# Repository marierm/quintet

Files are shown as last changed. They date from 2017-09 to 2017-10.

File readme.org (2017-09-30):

* Intro
  <2017-09-25 Mon> This repository contains all the files used for
  designing, building and playing the sponge.  This version is for the
  new sponge quintet.  The sponges are based on the Adafruit Feather
  M0 WiFi (with ATWINC1500 wifi chip).

* Instructions 
  Instructions on how to use the sponge with your comupter are in
  =scCode/instructions.org= or =scCode/instructions.pdf= .  They are
  in French only at this point.

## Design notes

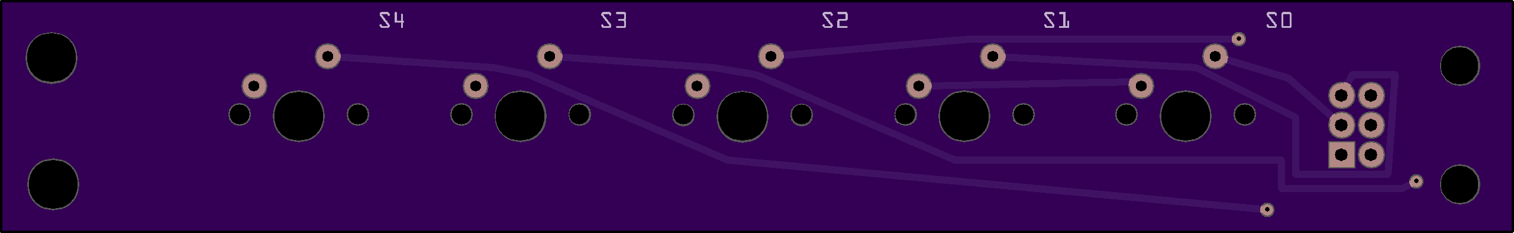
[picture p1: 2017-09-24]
pcb/buttonsTop.png

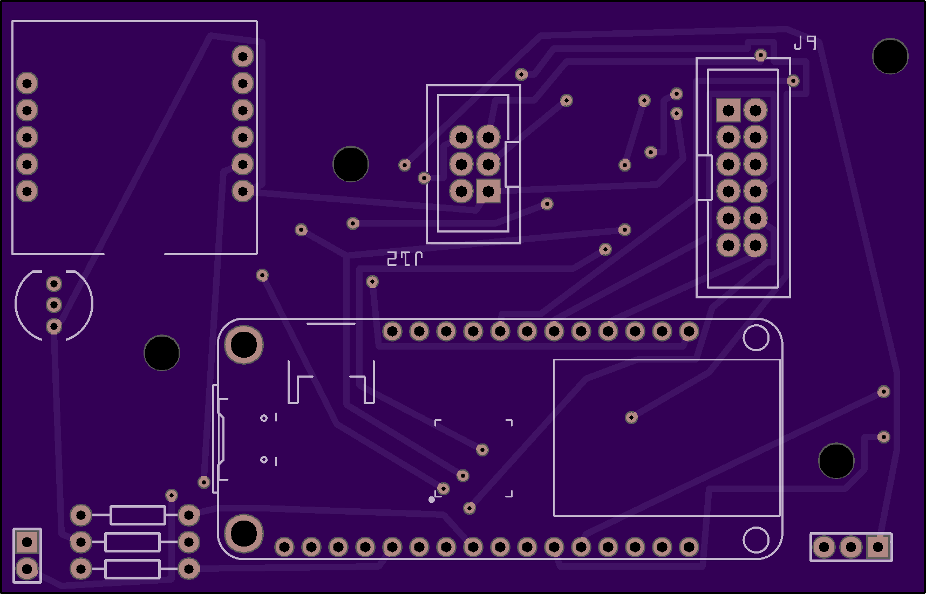
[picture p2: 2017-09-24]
pcb/mainTop.png

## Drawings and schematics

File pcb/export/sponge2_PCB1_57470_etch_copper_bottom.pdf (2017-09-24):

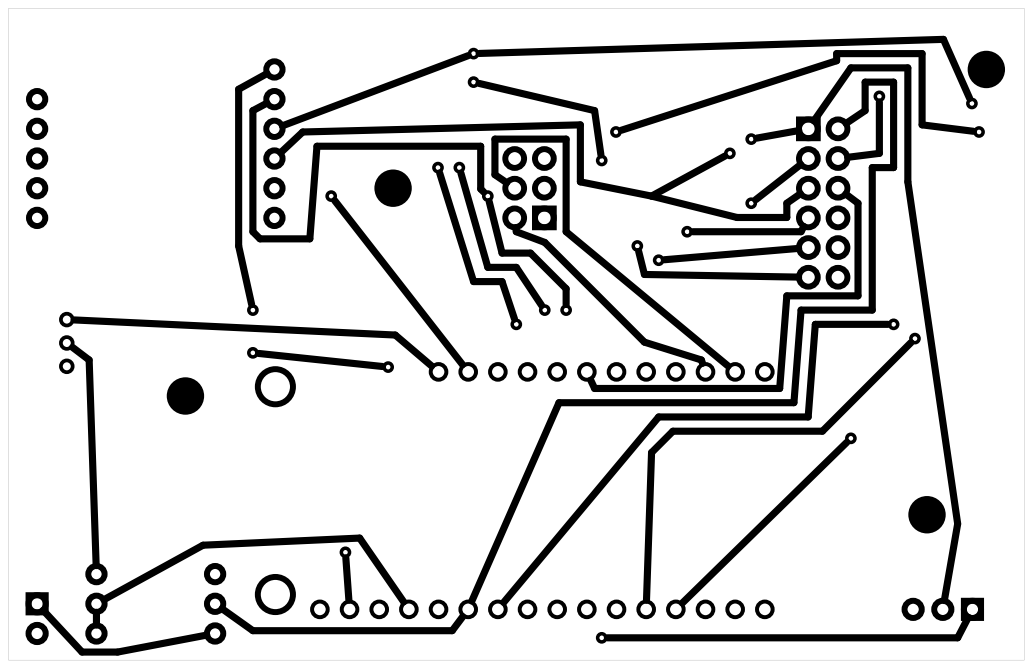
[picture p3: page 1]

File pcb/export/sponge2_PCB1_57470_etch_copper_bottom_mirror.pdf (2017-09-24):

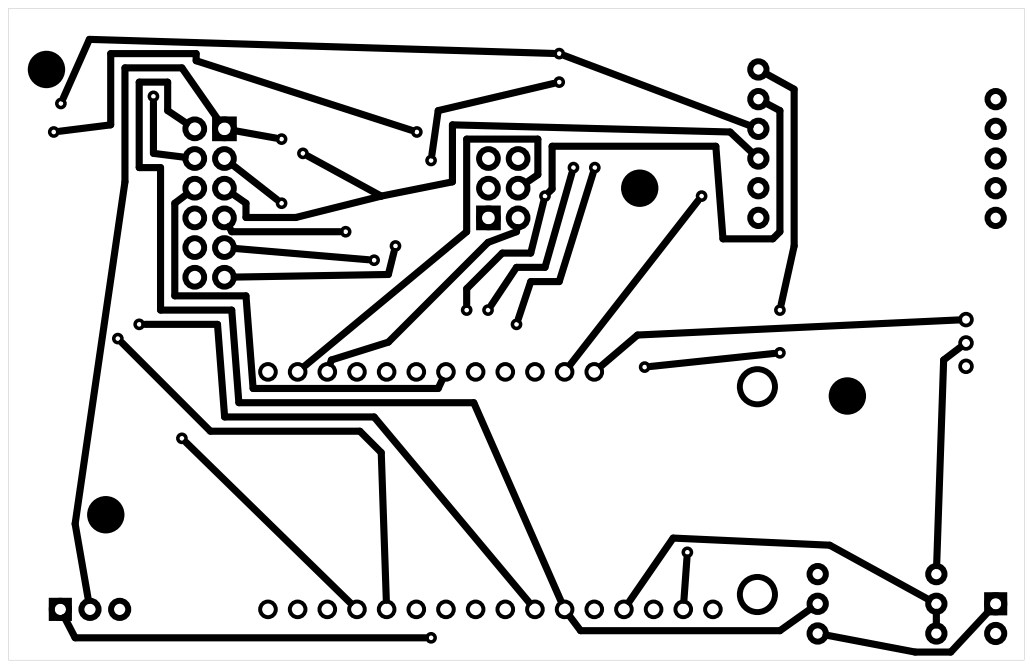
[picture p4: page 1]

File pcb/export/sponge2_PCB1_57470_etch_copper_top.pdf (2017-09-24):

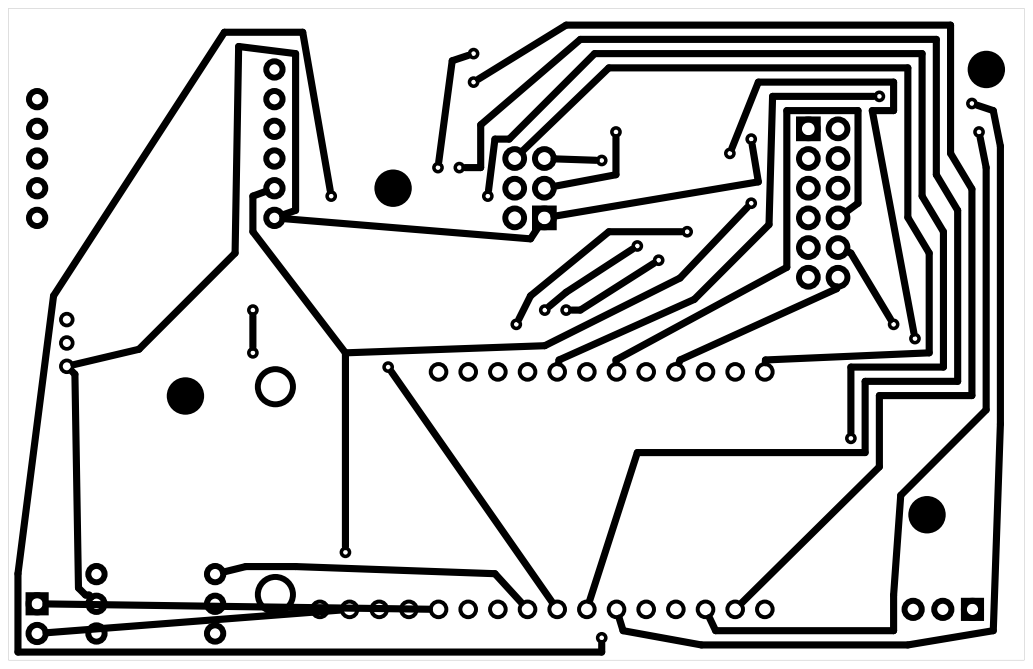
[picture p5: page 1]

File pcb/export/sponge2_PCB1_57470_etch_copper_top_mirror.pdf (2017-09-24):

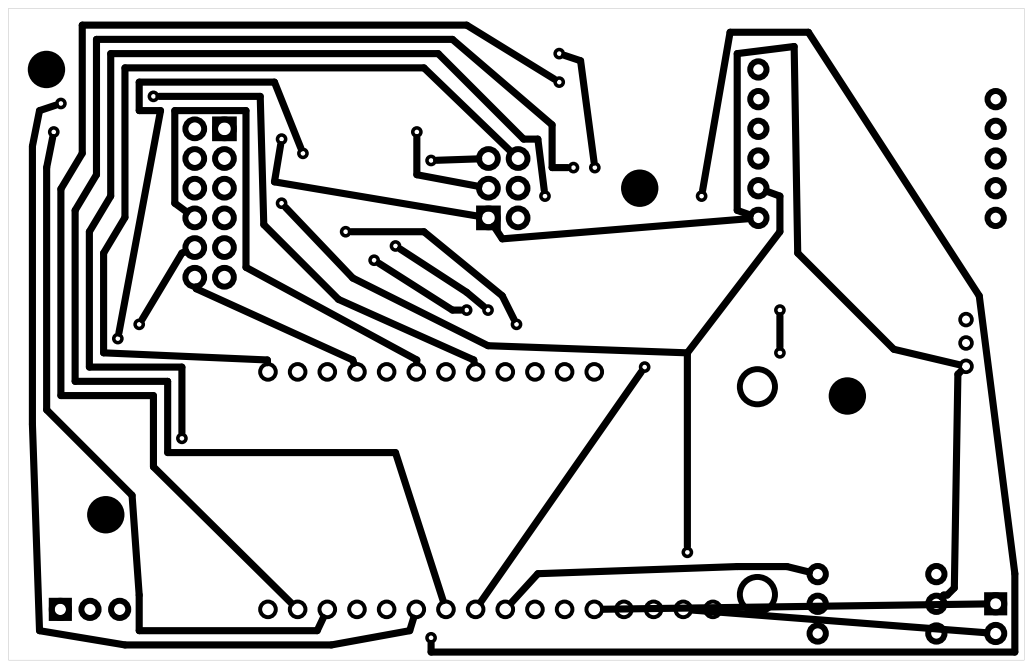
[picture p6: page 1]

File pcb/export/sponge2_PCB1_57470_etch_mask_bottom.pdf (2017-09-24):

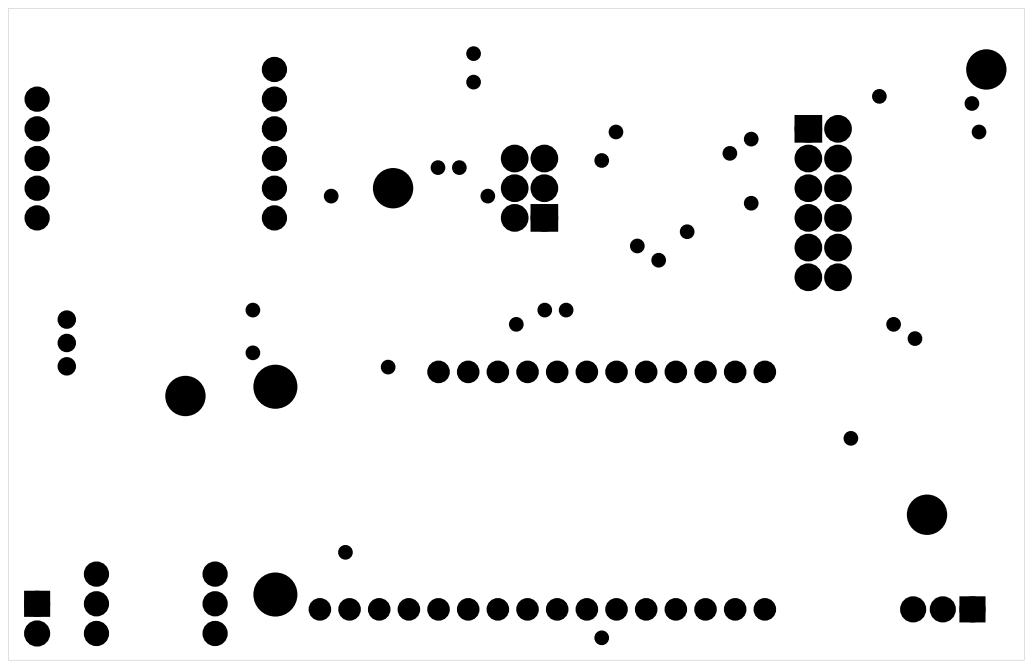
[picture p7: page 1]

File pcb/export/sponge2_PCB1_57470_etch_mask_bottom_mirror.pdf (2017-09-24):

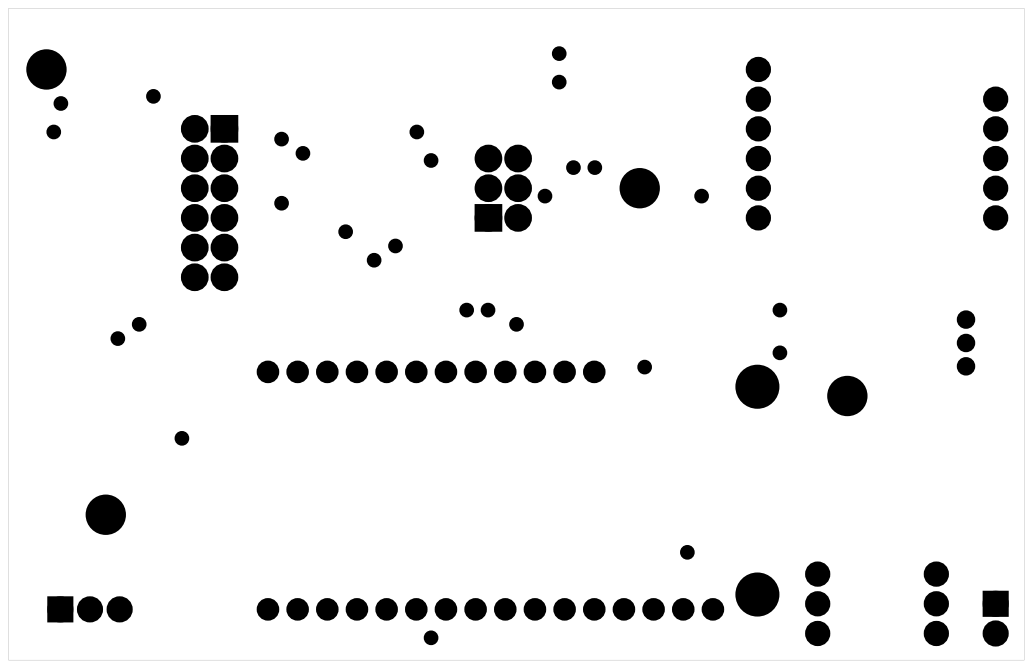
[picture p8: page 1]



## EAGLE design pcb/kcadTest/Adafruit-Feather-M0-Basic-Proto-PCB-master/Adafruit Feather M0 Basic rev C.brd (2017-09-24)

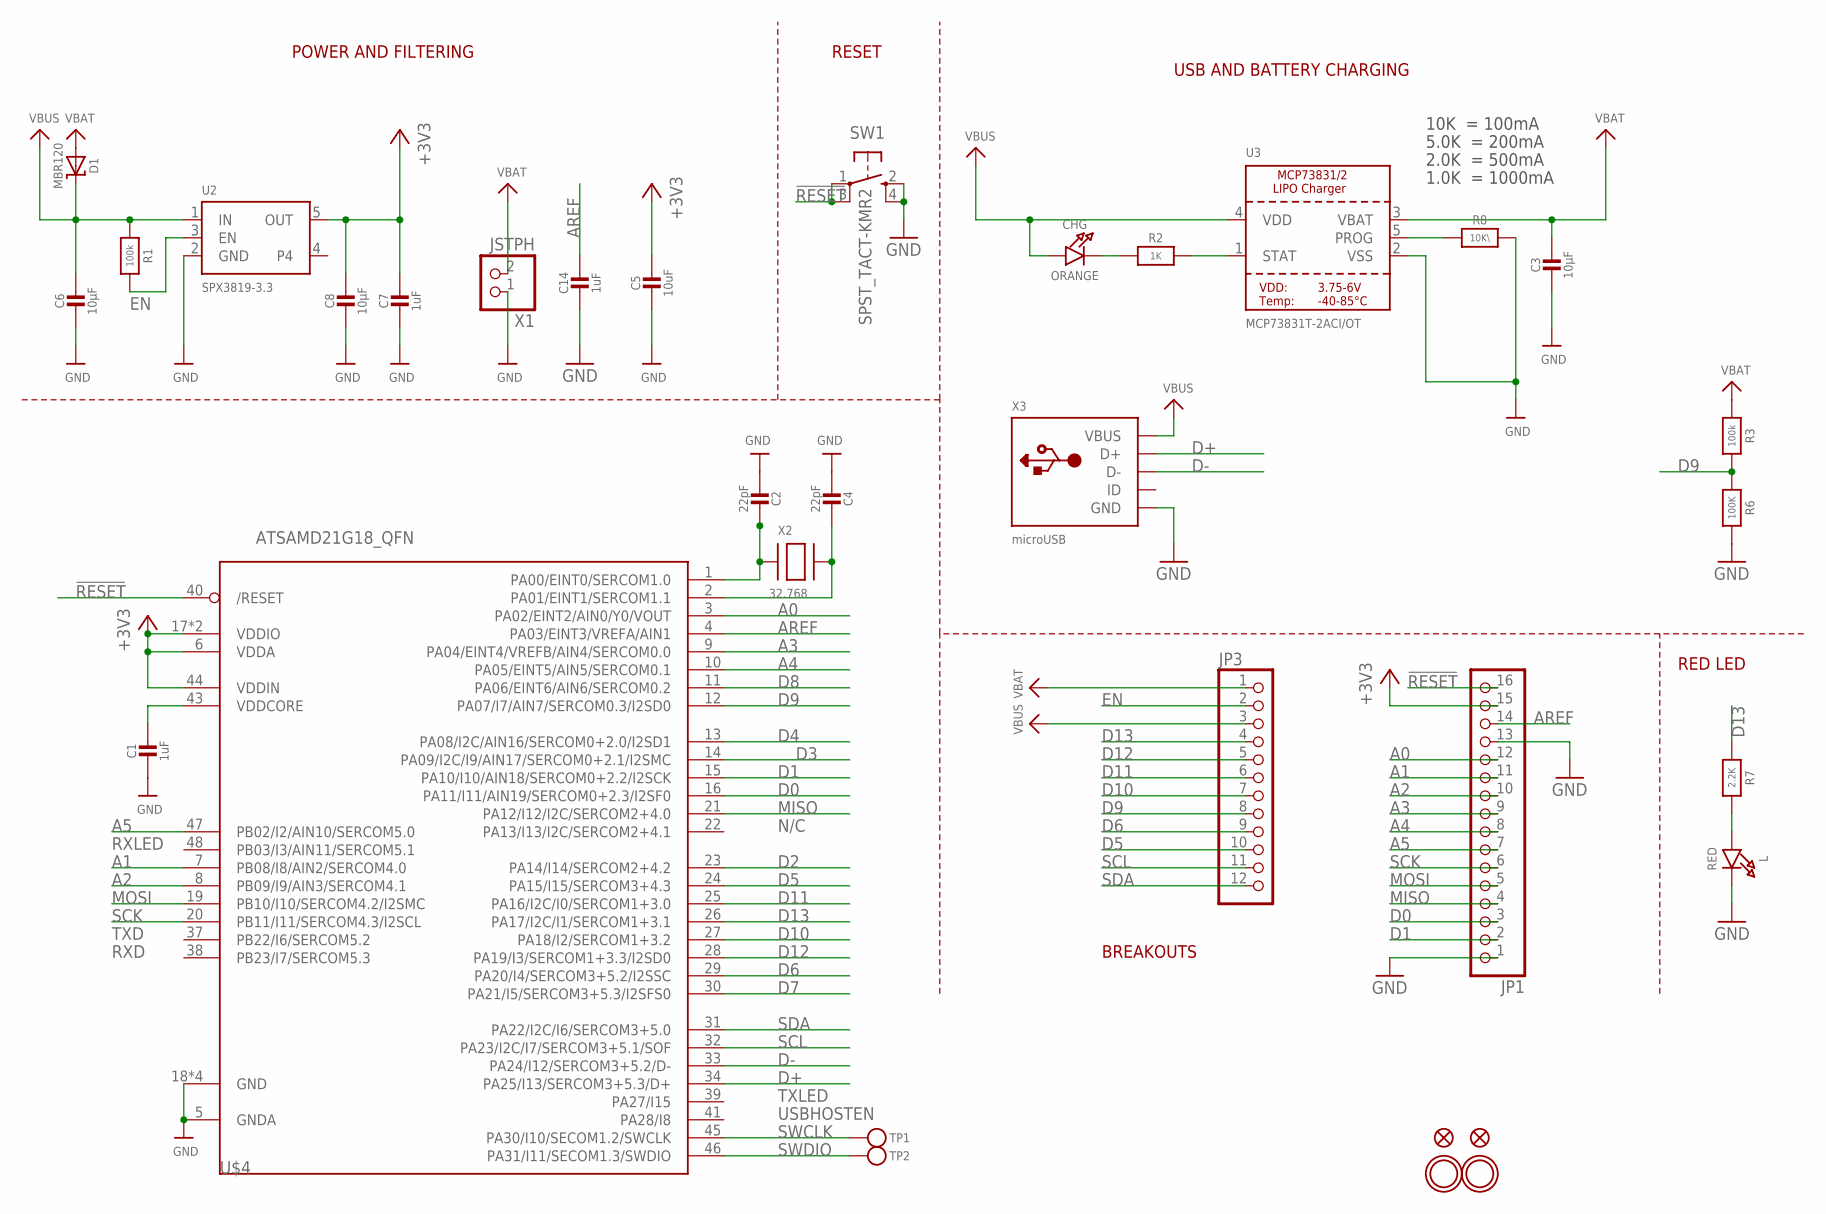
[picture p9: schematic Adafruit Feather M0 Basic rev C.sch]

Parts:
C1, C7, C14: 1uF; 0603-NO
C2, C4: 22pF; 0603-NO
C3, C6, C8: 10µF; 0805-NO
C5: 10uF; 0805-NO
CHG: ORANGE; CHIPLED_0805_NOOUTLINE
D1: MBR120; SOD-123
JP1: HEADER-1X16ROUND; 1X16_ROUND
JP3: HEADER-1X12; 1X12_ROUND
L: RED; CHIPLED_0805_NOOUTLINE
R1, R3: 100k; 0603-NO
R2: 1K; 0603-NO
R6: 100K; 0603-NO
R7: 2.2K; 0603-NO
R8: 10K\; 0603-NO
SW1: SPST_TACT-KMR2; KMR2
TP1, TP2: TESTPOINTROUND1.5MM; TESTPOINT_ROUND_1.5MM
U2: SPX3819-3.3; SOT23-5
U3: MCP73831T-2ACI/OT; SOT23-5
U$4: ATSAMD21G18_QFN; TQFN48_7MM
U$31, U$32: MOUNTINGHOLE2.5; MOUNTINGHOLE_2.5_PLATED
U$34, U$35: FIDUCIAL""; FIDUCIAL_1MM
X1: JSTPH; JSTPH2
X2: 32.768; XTAL3215
X3: microUSB; 4UCONN_20329_V2

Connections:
!RESET: JP1.16, SW1.1, SW1.3 (P1), U$4.40 (/RESET)
+3V3: C5.1, C7.1, C8.1, JP1.15, U2.5 (OUT), U$4.6 (VDDA), U$4.17 (VDDIO), U$4.36 (VDDIO), U$4.44 (VDDIN)
A0: JP1.12, U$4.3 (PA02/EINT2/AIN0/Y0/VOUT)
A1: JP1.11, U$4.7 (PB08/I8/AIN2/SERCOM4.0)
A2: JP1.10, U$4.8 (PB09/I9/AIN3/SERCOM4.1)
A3: JP1.9, U$4.9 (PA04/EINT4/VREFB/AIN4/SERCOM0.0)
A4: JP1.8, U$4.10 (PA05/EINT5/AIN5/SERCOM0.1)
A5: JP1.7, U$4.47 (PB02/I2/AIN10/SERCOM5.0)
AREF: C14.1, JP1.14, U$4.4 (PA03/EINT3/VREFA/AIN1)
D0: JP1.3, U$4.16 (PA11/I11/AIN19/SERCOM0+2.3/I2SF0)
D1: JP1.2, U$4.15 (PA10/I10/AIN18/SERCOM0+2.2/I2SCK)
D2: U$4.23 (PA14/I14/SERCOM2+4.2)
D3: U$4.14 (PA09/I2C/I9/AIN17/SERCOM0+2.1/I2SMC)
D4: U$4.13 (PA08/I2C/AIN16/SERCOM0+2.0/I2SD1)
D5: JP3.10, U$4.24 (PA15/I15/SERCOM3+4.3)
D6: JP3.9, U$4.29 (PA20/I4/SERCOM3+5.2/I2SSC)
D7: U$4.30 (PA21/I5/SERCOM3+5.3/I2SFS0)
D8: U$4.11 (PA06/EINT6/AIN6/SERCOM0.2)
D9: JP3.8, R3.2, R6.1, U$4.12 (PA07/I7/AIN7/SERCOM0.3/I2SD0)
D10: JP3.7, U$4.27 (PA18/I2/SERCOM1+3.2)
D11: JP3.6, U$4.25 (PA16/I2C/I0/SERCOM1+3.0)
D12: JP3.5, U$4.28 (PA19/I3/SERCOM1+3.3/I2SD0)
D13: JP3.4, R7.1, U$4.26 (PA17/I2C/I1/SERCOM1+3.1)
D+: U$4.34 (PA25/I13/SERCOM3+5.3/D+), X3.D+
D-: U$4.33 (PA24/I12/SERCOM3+5.2/D-), X3.D-
EN: JP3.2, R1.2, U2.3 (EN)
GND: C1.2, C2.2, C3.2, C4.2, C5.2, C6.2, C7.2, C8.2, C14.2, JP1.1, JP1.13, L.C, R6.2, R8.2, SW1.2 (S), SW1.4 (S1), U2.2 (GND), U3.2 (VSS), U$4.5 (GNDA), U$4.18 (GND), U$4.35 (GND), U$4.42 (GND), U$4.THERMAL (GND), X1.1, X3.BASE@1 (GND), X3.BASE@2 (GND), X3.GND, X3.SPRT@1 (GND), X3.SPRT@2 (GND), X3.SPRT@3 (GND), X3.SPRT@4 (GND)
MISO: JP1.4, U$4.21 (PA12/I12/I2C/SERCOM2+4.0)
MOSI: JP1.5, U$4.19 (PB10/I10/SERCOM4.2/I2SMC)
unnamed: CHG.C, R2.1
unnamed: L.A, R7.2
unnamed: R2.2, U3.1 (STAT)
unnamed: R8.1, U3.5 (PROG)
unnamed: C2.1, U$4.1 (PA00/EINT0/SERCOM1.0), X2.P$1
unnamed: C4.1, U$4.2 (PA01/EINT1/SERCOM1.1), X2.P$2
SCK: JP1.6, U$4.20 (PB11/I11/SERCOM4.3/I2SCL)
SCL: JP3.11, U$4.32 (PA23/I2C/I7/SERCOM3+5.1/SOF)
SDA: JP3.12, U$4.31 (PA22/I2C/I6/SERCOM3+5.0)
SWCLK: TP1.P$1, U$4.45 (PA30/I10/SECOM1.2/SWCLK)
SWDIO: TP2.P$1, U$4.46 (PA31/I11/SECOM1.3/SWDIO)
VBAT: C3.1, D1.A, JP3.1, R3.1, U3.3 (VBAT), X1.2
VBUS: C6.1, CHG.A, D1.C, JP3.3, R1.1, U2.1 (IN), U3.4 (VDD), X3.VBUS
VDDCORE: C1.1, U$4.43 (VDDCORE)

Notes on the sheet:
POWER AND FILTERING
RESET
10K = 100mA
5.0K = 200mA
2.0K = 500mA
1.0K = 1000mA
N/C
TXLED
USBHOSTEN
RXLED
TXD
RXD
USB AND BATTERY CHARGING
BREAKOUTS
RED LED

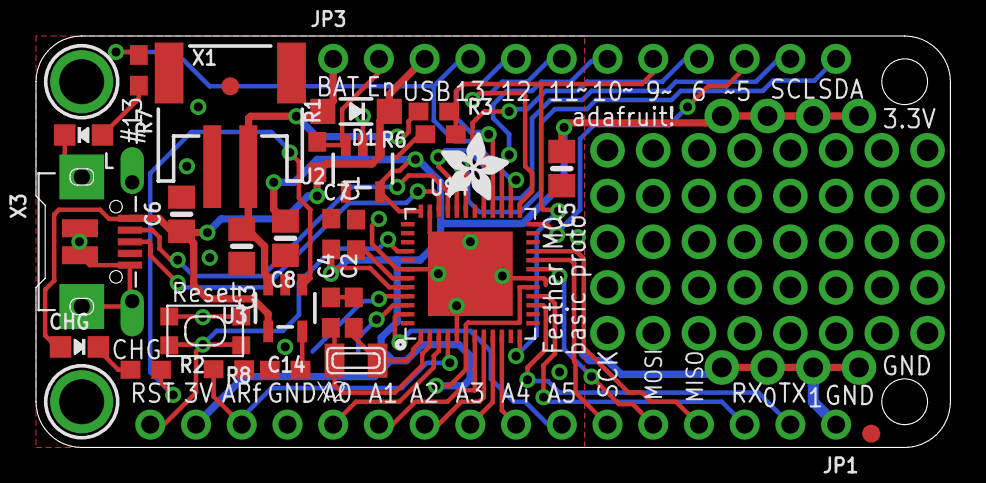
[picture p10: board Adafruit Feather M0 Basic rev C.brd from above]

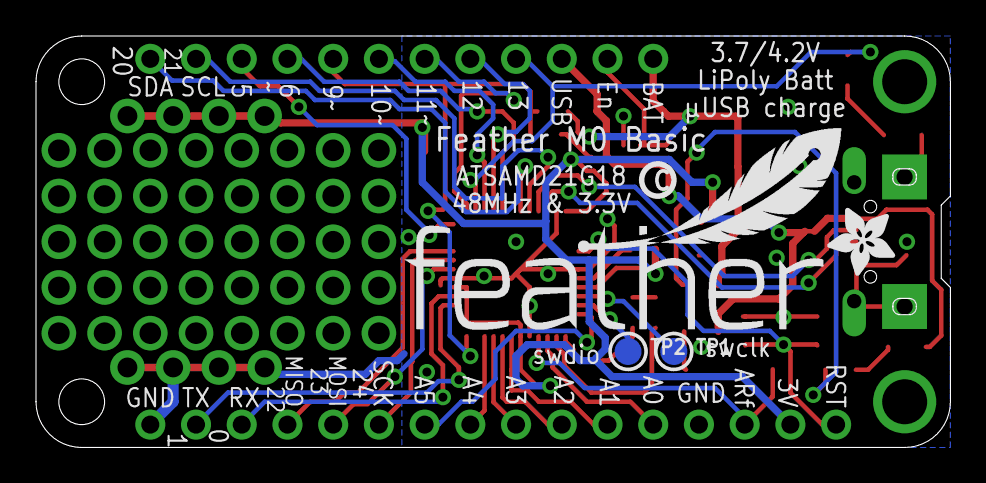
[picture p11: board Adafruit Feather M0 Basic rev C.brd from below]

Board: 2 copper layers, 50.8 x 22.9 mm, 37 parts (5 on the bottom side), 38 nets.

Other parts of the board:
U$7, U$12: ADAFRUIT_3.5MM
U$9: FEATHERLOGO
U$13: PCBFEAT-REV-040

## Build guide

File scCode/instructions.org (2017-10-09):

#+OPTIONS: ':nil *:t -:t ::t <:t H:3 \n:nil ^:t arch:headline
#+OPTIONS: author:t broken-links:nil c:nil creator:nil
#+OPTIONS: d:(not "LOGBOOK") date:t e:t email:nil f:t inline:t num:t
#+OPTIONS: p:nil pri:nil prop:nil stat:t tags:t tasks:t tex:t
#+OPTIONS: timestamp:t title:t toc:nil todo:t |:t
#+TITLE: Instructions pour utiliser l'éponge.
#+DATE: 
#+AUTHOR: Martin Marier
#+EMAIL: martin@martinmarier.com
#+LANGUAGE: fr
#+SELECT_TAGS: export
#+EXCLUDE_TAGS: noexport
#+CREATOR: Emacs 25.3.1 (Org mode 9.1)

* Installer SuperCollider et les plugins
  La version la plus récente de SC est disponible ici:
  http://supercollider.github.io/download Nous utilisons actuellement la
  version 3.8.0.

  Les plugins sont disponibles ici:
  https://github.com/supercollider/sc3-plugins/releases Nous utilisons
  actuellement la version 3.8.0.

  Une fois l'archive ZIP dépaquetée, le dossier =SC3plugins= et tout
  son contenu doit être placé dans ce dossier (sur Mac):

  =/Users/yourUserName/Library/Application Support/SuperCollider/Extensions=

  Créez le dossier =Extensions= au besoin.

  Pour connaître le dossier dans lequel vous devez déposer les
  =SC3plugins= sur une autre plateforme (Windows ou Linux), démarrez
  SuperCollider et cliquez sur l'item /Open user support directory/ du
  menu /File/.

* Installer tous les Quarks nécessaires
  La liste des quarks nécessaires est dans le fichier
  =scCode/installation.scd=

  Vous devez ouvrir ce document avec SuperCollider et exécuter le bloc de code
  qui est entre parenthèses.

  Pour exécuter le bloc, placez le curseur sur la première parenthèse et
  appuyez sur Command+Enter (ou Ctrl+Enter).

* Installer les mmExtensions
  Téléchargez les mmExtensions ici: https://github.com/marierm/mmExtensions

  Le fichier ZIP doit être dépaqueté dans ce dossier (sur mac):

  =/Users/yourUserName/Library/Application Support/SuperCollider/Extensions=

  Créez le dossier =Extensions= au besoin.

* Configurer l'éponge
  Lors de sa mise sous tension, l'éponge tente de se connecter au
  dernier point d'accès WiFi (un routeur sans fil) auquel elle s'est
  connectée.

  Si ce point d'accès n'est pas disponible, l'éponge devient elle-même
  un point d'accès dont le nom est =wifi101-XXXX=, où =XXXX=
  représente les quatre derniers caractères de l'adresse MAC de
  l'éponge.  L'adresse MAC -- unique pour chaque appareil pouvant se
  connecter à un résea WiFi -- est imprimée sur le module WiFi de
  l'éponge.

  Il faudra alors se connecter à ce réseau Wifi et, de là, accéder à
  la page web servie par l'éponge à l'adresse http://192.168.1.1 .
  Sur cette page, entrez le nom de votre point d'accès et le mot de
  passe correspondant.  L'éponge se connectera alors automatiquement
  au point d'accès que vous avez entré.  (À partir de ce moment, la
  page http://192.168.1.1 n'est plus accessible.  Il est donc normal
  que le navigateur utilisé affiche un message d'erreur.)

* Démarrer l'éponge en mode solo
  Ouvrez le fichier scCode/solo.scd dans SuperCollider et exécuter le bloc de code
  qui est entre parenthèses.

  Pour exécuter le bloc, placez le curseur sur la première parenthèse
  et appuyez sur Command+Enter (ou Ctrl+Enter).

  L'éponge est prête quand le message =sponge_solo ready.= apparaît dans la fenêtre
  =Post= de SuperCollider.

* Messages OSC
  (Vous n'avez pas besoin de comprendre tout ça.)

  L'éponge envoie des messages OSC en /multicast/ à l'adresse
  =224.0.0.1= sur le port 50501, à partir du port 50502.  Un seul
  message est envoyé à chaque 20 millisecondes.  L'adresse est
  =/sponge=.  Elle est suivie de neuf paramètres (tous des entiers):
  =acc1x=, =acc1y=, =acc1z=, =acc2x=, =acc2y=, =acc2z=, =fsr1=,
  =fsr2=, =buttons= .

  Les accéléromètres ont des valeurs 16 bits signées, les fsr ont des
  valeurs 12 bits non signées, et les boutons sont représentés par les
  10 bits les moins significatifs d'un entier à 32 bits.

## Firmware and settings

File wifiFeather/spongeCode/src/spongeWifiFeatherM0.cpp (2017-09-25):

#include "SparkFunLSM6DS3.h"
#include <SPI.h>
#include <Wire.h>
#include <WiFi101.h>
#include <WiFiUdp.h>
#include <OSCMessage.h>
#include <OSCBundle.h>
#include <OSCData.h>
void SLIPSerialWrite(int value);
void sendSpongeOSC();
void initAccelGyro();

//SLIP for wired serial backup.
const byte END=192;
const byte ESC=219;
const byte ESC_END=220;
const byte ESC_ESC=221;


// const char* ssid     = "mmLinksysEA7500-2.4";
// const char* ssid     = "sideroxylon";
// const char* password = "ddcgrvc4zw";
 
WiFiUDP udp; // A UDP instance to let us send and receive packets over UDP
// const IPAddress outIp(192,168,109,103); // remote IP of your computer
const IPAddress outIp(224,0,0,1); // remote IP for multicast
// const IPAddress outIp(10,42,0,1); // remote IP of your computer
const unsigned int outPort = 50501; // remote port to receive OSC
const unsigned int localPort = 50502; // local port to listen for OSC packets


// const int butPins[10] = { 0,1,20,21,5,6,9,10,11,12 };
// GPIO 9 can be used as A7 to monitor battery voltage.
// Use GPIO 16 (A2) instead.
const int butPins[10] = { 0,1,20,21,5,6,16,10,11,12 };
const int ledPin = 17; // Controler pin for LED strip.

OSCErrorCode error;

LSM6DS3 SensorOne( SPI_MODE, 18 );  // pin A4 on feather
LSM6DS3 SensorTwo( SPI_MODE, 19 );  // pin A5 on feather

void setup(){
  //Configure pins for Adafruit ATWINC1500 Feather
  WiFi.setPins(8,7,4,2);
  Serial.begin(115200);
  analogReadResolution(12);
  // Make butPins INPUT pins with pull up resistor.
  for (int i=0; i < 10; i++){
    pinMode(butPins[i], INPUT_PULLUP);
  }

  // pinMode(12, INPUT);
  /* Wire.begin(); */

  delay(100);
  // We start by connecting to a WiFi network
 

  // Serial.println();
  // Serial.print("Connecting to ");
  // Serial.println(ssid);
  
  // WiFi.begin(ssid, password);
  // WiFi.begin(ssid,password);
  WiFi.beginProvision();
  
  while (WiFi.status() != WL_CONNECTED) {
    delay(500);
    Serial.write(END);
  }
 
  // Serial.println("");
  // Serial.println("WiFi connected");  
  // Serial.print("IP address: ");
  // Serial.println(WiFi.localIP());

  // Serial.print("SSID: ");
  // Serial.println(WiFi.SSID());

  // Serial.println("Starting UDP");
  // udp.begin(localPort);
  udp.beginMulti(outIp, localPort);
  // Serial.print("Local port: ");
  // Serial.println(localPort);


  delay(1000);
  initAccelGyro();

  // SensorOne.begin();
  // SensorTwo.begin();
  if( SensorOne.begin() != 0 ) {
    Serial.write(END);
    Serial.println("Problem starting the sensor with CS @ Pin 18 (A4).");
    Serial.write(END);
  } else {
    Serial.write(END);
    Serial.println("Sensor with CS @ Pin 18 (A4) started.");
    Serial.write(END);
  }
  if( SensorTwo.begin() != 0 ) {
    Serial.write(END);
    Serial.println("Problem starting the sensor with CS @ Pin 19 (A5).");
    Serial.write(END);
  } else {
    Serial.write(END);
    Serial.println("Sensor with CS @ Pin 19 (A5) started.");
    Serial.write(END);
  }
}

void loop(){
  OSCMessage message;
  int size = udp.parsePacket();

  if (size) {
    while (size--) {
      message.fill(udp.read());
    }
    if (!message.hasError()) {
      /* message.dispatch("/set_register", osc_set_register); */
    } else {
      error = message.getError();
      Serial.print("error: ");
      Serial.println(error);
    }
  }

  // Serial.println( (SensorOne.readRawAccelX() >> 6) + 512);
  // Serial.print(SensorOne.readRawAccelY());
  // Serial.print(SensorOne.readRawAccelZ());
  // Serial.print(SensorOne.readRawGyroX());
  // Serial.print(SensorOne.readRawGyroY());
  // Serial.print(SensorOne.readRawGyroZ());

  sendSpongeOSC();
  
  // int anal0 = analogRead(1);
  // OSCBundle bndl;

  // wait a bit.
  // delay(5);
  // Serial.println(WiFi.SSID());
  delay(20); // 15 seems to be too short.
  
  // delay(1);
  // delayMicroseconds(10);

  // if (WiFi.status() != WL_CONNECTED) {
  //   // WiFi.end();
  //   while (WiFi.begin(ssid) != WL_CONNECTED) {
  //     delay(500);
  //     Serial.print(".");
  //   }
  //   Serial.print("Reconnected to ");
  //   Serial.print(ssid);
  // }
}

void initAccelGyro(){
  //Over-ride default settings if desired
  SensorOne.settings.gyroEnabled = 1;  //Can be 0 or 1
  SensorOne.settings.gyroRange = 2000;   //Max deg/s.  Can be: 125, 245, 500, 1000, 2000
  SensorOne.settings.gyroSampleRate = 1666;   //Hz.  Can be: 13, 26, 52, 104, 208, 416, 833, 1666
  SensorOne.settings.gyroBandWidth = 400;  //Hz.  Can be: 50, 100, 200, 400;
  SensorOne.settings.accelEnabled = 1;
  SensorOne.settings.accelRange = 2;      //Max G force readable.  Can be: 2, 4, 8, 16
  SensorOne.settings.accelSampleRate = 13330;  //Hz.  Can be: 13, 26, 52, 104, 208, 416, 833, 1666, 3332, 6664, 13330
  SensorOne.settings.accelBandWidth = 400;  //Hz.  Can be: 50, 100, 200, 400;
  SensorOne.settings.fifoModeWord = 0;  //FIFO mode.

    //Over-ride default settings if desired
  SensorTwo.settings.gyroEnabled = 1;  //Can be 0 or 1
  SensorTwo.settings.gyroRange = 2000;   //Max deg/s.  Can be: 125, 245, 500, 1000, 2000
  SensorTwo.settings.gyroSampleRate = 1666;   //Hz.  Can be: 13, 26, 52, 104, 208, 416, 833, 1666
  SensorTwo.settings.gyroBandWidth = 400;  //Hz.  Can be: 50, 100, 200, 400;
  SensorTwo.settings.accelEnabled = 1;
  SensorTwo.settings.accelRange = 2;      //Max G force readable.  Can be: 2, 4, 8, 16
  SensorTwo.settings.accelSampleRate = 13330;  //Hz.  Can be: 13, 26, 52, 104, 208, 416, 833, 1666, 3332, 6664, 13330
  SensorTwo.settings.accelBandWidth = 400;  //Hz.  Can be: 50, 100, 200, 400;
  SensorTwo.settings.fifoModeWord = 0;  //FIFO mode.

  //FIFO mode.  Can be:
  //  0 (Bypass mode, FIFO off)
  //  1 (Stop when full)
  //  3 (Continuous during trigger)
  //  4 (Bypass until trigger)
  //  6 (Continous mode)
}


void sendSpongeOSC() {
  int compButVal=0; // composed into a single 32 bit integer (only 10 are used).

  OSCMessage msg("/sponge"); // 8 bytes
  // OSCMessage time("/time");
  // uint64_t timetag;
  // msg.add(anal0);
  // types are ,iiiiiiiiiiiii // 4 bytes
  msg.add(int(SensorOne.readRawAccelX())); // int 0
  msg.add(int(SensorOne.readRawAccelY())); // int 1
  msg.add(int(SensorOne.readRawAccelZ())); // int 2
  // msg.add(int(SensorOne.readRawGyroX()));
  // msg.add(int(SensorOne.readRawGyroY()));
  // msg.add(int(SensorOne.readRawGyroZ()));
  msg.add(int(SensorTwo.readRawAccelX())); // int 3
  msg.add(int(SensorTwo.readRawAccelY())); // int 4
  msg.add(int(SensorTwo.readRawAccelZ())); // int 5
  // msg.add(int(SensorTwo.readRawGyroX()));
  // msg.add(int(SensorTwo.readRawGyroY()));
  // msg.add(int(SensorTwo.readRawGyroZ()));
  for (int i=0; i < 2; i ++){ // ints 6 and 7
    msg.add(int(analogRead(i)));
  };


  for (int i=0; i < 10; i ++){
    compButVal |= ( digitalRead(butPins[i]) << (9-i));
    /* La ligne précédente place les valeurs binaires de chacun des boutons
       dans un seul entier à 16 bit.  Si on représente l'entier en binaire:
       (b01001011001 = d601),  on a une représentation des boutons activés.
       Dans ce cas, les boutons 0,3,4,6 et 9 sont enfoncés.
    */
  };

  msg.add(compButVal ^ 1023); // 4 bytes  (^ is a bitwise XOR)

  // bndl.add("/sponge").add("one");
  // msg.add(1).add(2).add(3).add(4).add(5).add(6).add(7).add(8).add(9).add(10).add(11).add(12); // 48 bytes of arbitrary ints.
  // Total size is 64 bytes. (excluding the UDP packet stuff)
  // time.add((uint32_t)micros() & 0xFFFF);
  udp.beginPacket(outIp, outPort);
  // bndl.setTimetag(oscTime());
  msg.send(udp);
  udp.endPacket();
  msg.empty();
}


void SLIPSerialWrite(int value){
  if(value == END) {
    Serial.write(ESC);
    Serial.write(ESC_END);
    return;
  } else if (value == ESC) {
    Serial.write(ESC);
    Serial.write(ESC_ESC);
    return;
  } else {
    Serial.write(value);
    return;
  }
}

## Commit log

2017-09-24 First commit. A lot of stuff.
    [Adafruit Feather M0 Basic rev C.brd, Adafruit Feather M0 Basic rev C.sch, sponge.kicad_pcb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]
2017-09-25 Sponge fixes and RPP details.
    [spongeWifiFeatherM0.cpp]
2017-10-09 Remove a lot of useless button functions.
2017-10-10 Add reset octave on button 8 (or right 2).
2018-01-15 Change BP for ~fms.
    This was the final stop to switch to cFm and cSponge which remove
    dependancies on ChuchLib (just for fm synth, though, not for
    everything).
2018-01-16 New buttons for cLooper.
    In pitch and harmo modes, button L5 (which is 0 for the code) is not
    used for pitch classes or chords anymore. It is used as a shift
    button for R2. Holding L5 and pressing R2 stops loop playback. (With
    a beautiful fade.)

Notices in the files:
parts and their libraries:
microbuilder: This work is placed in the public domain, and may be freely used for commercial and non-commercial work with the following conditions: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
